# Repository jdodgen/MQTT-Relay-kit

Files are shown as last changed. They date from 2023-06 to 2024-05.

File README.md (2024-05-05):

<h1>MQTT-Relay-kit</h1>
MicroPython and STL's including openSCAD code to make a complete MQTT Client Relay.
<br>
This "kit" includes both the running python code as well as the scad/stl files to make a 3d printed enclosure.
<br>
The parts to build this are:<br>
<b>ESP32-S2 Mini WiFi Board</b><br>
<b>HiLetgo D1 Mini Relay Shield</b> or equivilant<br><pr>
Different relay boards may require changing the lid in the openSCAD code

LOG
<pre>
9-June-2023
This is still a work in progress current: 9-June-2023.<br>
4-May-2024
The hardware is solid, for code improvements see the other MQTT projects

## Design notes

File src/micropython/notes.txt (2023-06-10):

# This is a build on a esp32-s2 on a D1 Mini card
# after powering up
# Press AND HOLD the button labelled 0
# then press and release the RESET button, then release 0
# and it should appear as a serial device.
# This is common to all ESP32-S2's, it's not just "S2 Mini" board.
# note /dev/ttyACM0 will need to have ownership changed or run commands as root sudo
#
# this makes things simpler so do this and logout and in
sudo usermod -a -G dialout $USER

# install tools 
sudo pip install esptool
sudo apt install picocom 
sudo pip install adafruit-ampy

# this is here for cut and paste

sudo chmod 666 /dev/ttyACM0

# if you had done this the above was not needed
sudo usermod -a -G dialout $USER

#now get the current MicroPython installed on the esp32s2
esptool.py --port /dev/ttyACM0 erase_flash
esptool.py --chip esp32s2 --port /dev/ttyACM0 write_flash -z 0x1000 GENERIC_S2-20230426-v1.20.0.bin

# now just press R (RST)  to continue
# R also may be needed after a power cycle

ampy --port /dev/ttyACM0 put main.py
ampy --port /dev/ttyACM0 put run.py
ampy --port /dev/ttyACM0 put relay.py
ampy --port /dev/ttyACM0 put boot.py
ampy --port /dev/ttyACM0 put mqtt_as.py

ampy --port /dev/ttyACM0 put relay_config.py

# test code - had to pull to do a diff
mkdir diff
ampy --port /dev/ttyACM0 get main.py  diff/main.py
ampy --port /dev/ttyACM0 get run.py diff/run.py
ampy --port /dev/ttyACM0 get relay.py diff/relay.py
ampy --port /dev/ttyACM0 get relay_config.py diff/relay_config.py
ampy --port /dev/ttyACM0 get boot.py diff/boot.py
ampy --port /dev/ttyACM0 get mqtt_as.py   diff/mqtt_as.py 

# test stuff

mosquitto_sub -h 192.168.0.173 -t "jed/relay1_status"

# sample test MQTT pubsub
mosquitto_sub -h 192.168.0.173 -t "jed/relay1_status"
mosquitto_pub -h 192.168.0.173 -t "jed/relay1" -m "on"

# REPL 
picocom -b 115200 /dev/ttyACM0
# some needed picocom commands
# CTRL-A CTRK-X  to exit
# import main   to run main or other py
# CTRL-C will stop some code

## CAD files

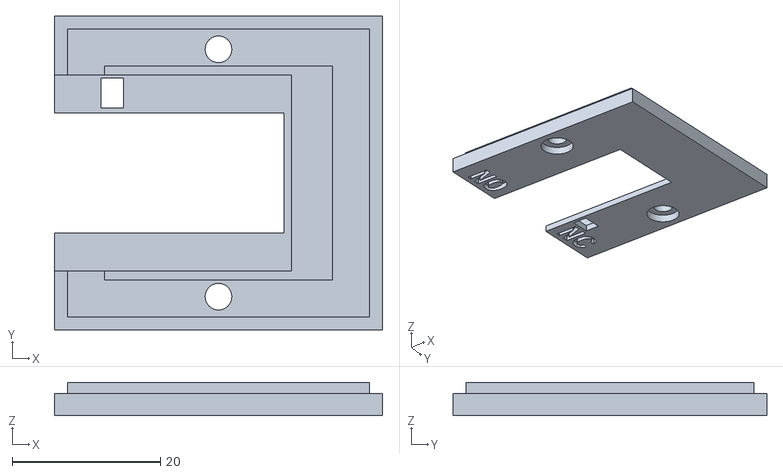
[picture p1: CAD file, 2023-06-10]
src/openscad/s2_relay_lid.stl
44.3 x 42.4 x 4.50

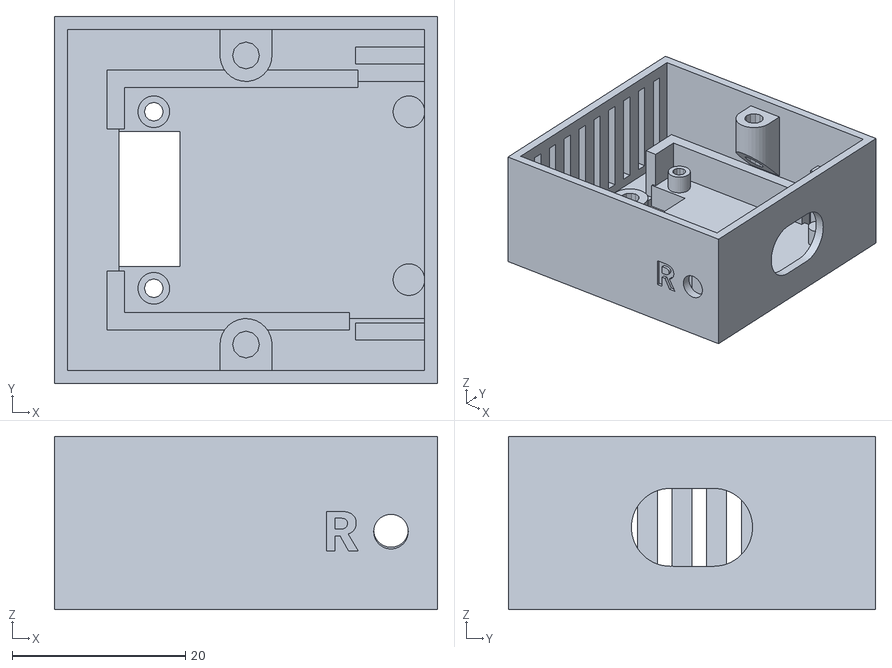
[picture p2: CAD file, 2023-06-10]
src/openscad/s2_relay_base.stl
44.3 x 42.4 x 20.0

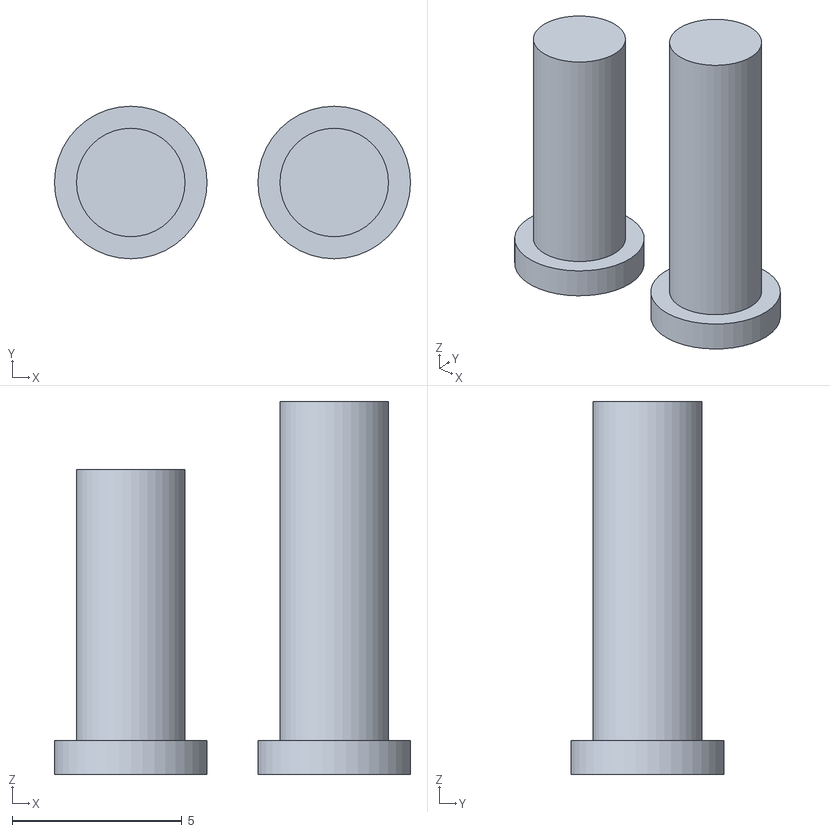
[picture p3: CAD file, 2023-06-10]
src/openscad/s2_relay_buttons.stl
10.5 x 4.50 x 11.0

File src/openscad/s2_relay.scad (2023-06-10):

/*
modular enclosure for ESP32-S2 style of wemos D1 Mini 
current shell lid is for a style of relay 
MIT 
Copyright 2023 James Dodgen

Permission is hereby granted, free of charge, to any person obtaining a copy of this software and associated documentation files (the “Software”), 
to deal in the Software without restriction, including without limitation the rights to use, copy, modify, merge, publish, distribute, 
sublicense, and/or sell copies of the Software, and to permit persons to whom the Software is furnished to do so, subject to the following conditions:

The above copyright notice and this permission notice shall be included in all copies or substantial portions of the Software.

THE SOFTWARE IS PROVIDED “AS IS”, WITHOUT WARRANTY OF ANY KIND, EXPRESS OR IMPLIED, INCLUDING BUT NOT LIMITED TO THE WARRANTIES OF MERCHANTABILITY, 
FITNESS FOR A PARTICULAR PURPOSE AND NONINFRINGEMENT. IN NO EVENT SHALL THE AUTHORS OR COPYRIGHT HOLDERS BE LIABLE FOR ANY CLAIM, 
DAMAGES OR OTHER LIABILITY, WHETHER IN AN ACTION OF CONTRACT, TORT OR OTHERWISE, ARISING FROM, OUT OF OR IN 
CONNECTION WITH THE SOFTWARE OR THE USE OR OTHER DEALINGS IN THE SOFTWARE.

version 1.1
*/

make_somthing = 1;    // 1 base, 2=lid, 3 buttons

if (make_somthing == 1) {
    make_s2_base();
} else if (make_somthing == 2) {
    make_relay_lid();
} else if (make_somthing == 3) {
    make_button();
    translate([6,0,0]) 
        make_button(long=true); // two needed, short for the "O" long for the "RST"
}

Mx_fn = 12; // self tapping 
M3_screw_hole = 3.1; 
M3_clearence_hole = 3.6; 
M3_head_clearence_hole = 6.3;

M2_5_screw_hole = 2.7; 
M2_5_clearence_hole = 3.1; 
M2_5_head_clearence_hole = 6.2;

M2_screw_hole = 2.16; 
M2_clearence_hole = 2.6; 

drill_length = 20;


shell_x = 34.3 + 10;   // adjustments off of S2 D1 Mini
shell_y = 25.4 + 17;
shell_z = 20;
shell_wall_thickness = 1.5;
shell_post_d = 7;



module make_s2_base() {
    difference()
    {
        union()
        {
            make_s2_mini_mount(front_stops=false);
            translate([-(shell_x-s2_x)+shell_wall_thickness,(-(shell_y-s2_y)/2),0])
            {
                shell();
            }
        }
        make_s2_mini_mount_cutout();
    }
}

lid_mount_Loc_1 = [shell_x/2,shell_wall_thickness,shell_z-2];
lid_mount_Loc_2 = [shell_x/2,shell_y-shell_wall_thickness,shell_z-2];

//shell();
module shell()
{
    difference()
    {
        cube([shell_x, shell_y, shell_z]) ;
        translate([shell_wall_thickness, shell_wall_thickness ,shell_wall_thickness])
        {
            cube([shell_x - (shell_wall_thickness*2), shell_y-shell_wall_thickness*2, shell_z]);
        }
        mid_y = shell_y/2;
        make_slot([0,mid_y,3],height=shell_z-5);
        make_slot([0,mid_y+4,3],height=shell_z-5);
        make_slot([0,mid_y-4,3],height=shell_z-5);
        make_slot([0,mid_y+8,3],height=shell_z-5);
        make_slot([0,mid_y-8,3],height=shell_z-5);
        make_slot([0,mid_y-12,3],height=shell_z-5);
        make_slot([0,mid_y+12,3],height=shell_z-5);
        make_slot([0,mid_y-16,3],height=shell_z-5);
        make_slot([0,mid_y+16,3],height=shell_z-5);
        translate([33,0.5,9])
            rotate([90,0,0])
                center_text("R", size=5, extrude=1.2);
        translate([33,shell_y+0.7,9])
            rotate([90,0,0])
                center_text("O", size=5, extrude=1.2);       
        
    }
    lid_mount(lid_mount_Loc_1, rot=0);
    lid_mount(lid_mount_Loc_2, rot=180); 
}

//make_relay_lid();
module make_relay_lid()
{
    hat_x = 32;
    hat_y = 26.5;
    lip_depth = 1.9;
    shrinkage = 0.25;
    lip_width = 5;

    rotate([0,180.0])  // print upside down
    difference()
    {
        union()
        {
            difference()
            {
                union()
                {
                    
                    color("orange") cube([shell_x, shell_y, shell_wall_thickness*2]);
                    difference()
                    {
                        translate([shrinkage+shell_wall_thickness, shrinkage+shell_wall_thickness,-shell_wall_thickness])
                        {
                            slop = (shrinkage+shell_wall_thickness);
                            lip_x = shell_x-slop*2;
                            lip_y = shell_y-slop*2;
                            difference()
                            {
                                cut_out_x = lip_x-lip_width*2;
                                cut_out_y = lip_y-lip_width*2;
                                color("green") cube([lip_x, lip_y, lip_depth]);
                                translate([(lip_x-cut_out_x)/2,(lip_y-cut_out_y)/2,0])
                                    cube([cut_out_x, cut_out_y, lip_depth]);
                            }
                        }
                    }
                }
                translate([shell_x-hat_x,(shell_y - hat_y)/2,-10]) 
                    cube([hat_x, hat_y, 20]);
                lid_mount_clearance_hole(lid_mount_Loc_1, rot=0);
                lid_mount_clearance_hole(lid_mount_Loc_2, rot=180);
            }
            relay_y = 16.2;
            relay_x= 31;
            relay_z = 10;
            difference()
            {
                translate([shell_x-relay_x-2,(shell_y - hat_y-2)/2,shell_wall_thickness+0.3]) 
                    color("purple") cube([relay_x+2,hat_y+2,shell_wall_thickness-0.3]);
                translate([shell_x-relay_x,(shell_y - relay_y)/2,0]) 
                    cube([relay_x,relay_y,relay_z]);
            }
        }
        /// cut outs
        translate([0,0,drill_length/2+shell_wall_thickness]) {
            lid_mount_clearance_hole(lid_mount_Loc_1, rot=0,hole_size=M3_head_clearence_hole);
            lid_mount_clearance_hole(lid_mount_Loc_2, rot=180,hole_size=M3_head_clearence_hole); 
        }
        translate([41,7,2])
            rotate([0,0,90])
                center_text("NO", size=5, extrude=2);  
        translate([41,35,2])
            rotate([0,0,90])
                center_text("NC", size=5, extrude=1.2);  
        // LED cutout
        translate([35,30,-5])
                cube([3,4,20]);
    }
}

module lid_mount(xyz,  width=6, height=8, rot=0) {
    
    echo ("rotate", rot);
    if (rot == 0) { 
        translate([xyz.x+width/2, xyz.y, xyz.z])
            rotate([0,180,rot])
                raw_lid_mount(width=6, height=8);
    } else if ((rot == -90) || (rot == 270 )) {
        translate([xyz.x, xyz.y-width/2, xyz.z])
            rotate([0,180,rot])
                raw_lid_mount(width=6, height=8);
    } else if (rot == 90) {
        translate([xyz.x, xyz.y+width/2, xyz.z])
            rotate([0,180,rot])
                raw_lid_mount(width=6, height=8);
    } else if (rot == 180) {
        translate([xyz.x-width/2, xyz.y, xyz.z])
            rotate([0,180,rot])
                raw_lid_mount(width=6, height=8);
    }
}

//lid_mount([10,10,-2], rot=180); 
//lid_mount_clearance_hole([10,10,-2], rot=180); 
module lid_mount_clearance_hole(xyz,  width=6, height=8, rot=0, hole_size=M3_clearence_hole) {
 
    echo ("rotate", rot);
    if (rot == 0) { 
        translate([xyz.x, xyz.y+width/2, -drill_length/2])
           cylinder(h=drill_length, d=hole_size, $fn=40);
    } else if ((rot == -90) || (rot == 270 )) {
        translate([xyz.x+width/2, xyz.y, -drill_length/2])
            cylinder(h=drill_length, d=hole_size, $fn=40);
    } else if (rot == 90) {
        translate([xyz.x-width/2, xyz.y, -drill_length/2])
            cylinder(h=drill_length, d=hole_size, $fn=40);
    } else if (rot == 180) {
        translate([xyz.x, xyz.y-width/2, -drill_length/2])
            cylinder(h=drill_length, d=hole_size, $fn=40);   
    }
}

//raw_lid_mount();
module raw_lid_mount(width=6, height=8) {
    raw_height =20;
    //screw_depth= height*0.75;
    difference() 
    { 
        cube([width, width,raw_height]);			
        // chop off at 45 
        rotate([-45,0,0]) 
            translate([0,-50,height])
                cube([width, 100, raw_height*2]);		
        // screw hole
        translate([width/2, width/2,-2]) 
            cylinder(h=raw_height, d=M3_screw_hole, $fn=Mx_fn);                  
        translate([width/2,width/2,-2]) 
            fillet(180,width/2, raw_height+2, $fn=30);
        translate([0,width/2,-2]) 
                fillet(-90,width/2, raw_height+2, $fn=30);
    }                   
}

*difference() {
    make_s2_mini_mount(button_guides=false);
    make_s2_mini_mount_cutout();
    //translate([10,-50,0]) cube([100,100,100]);
}

/* 
START Wemos S2 Mini mount code
*/
s2_y=25.4;
s2_x=34.3;
s2_thickness=4;

total_height = s2_thickness+3;
usb_c_hole_width = 14;
usb_c_hole_height = 9;

hole_offset_x = 3; 
hole1_offset_y = 2.5;
hole2_offset_y= hole1_offset_y+20.4;
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

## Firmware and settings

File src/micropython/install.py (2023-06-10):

import os
# this configures and installs router software
# change relay_config_template to your system/network
# the {}'s are replaced with MQTT Topic name
relay_config_template = """
ssid = 'JEDguest' 
passwd = '9098673852'
server = 'home-broker.local'
sub_topic = "{}"
pub_topic = "{}_status"
relay_pin = 35
"""
print("each relay must have a unique topic name")
print("input topic")
topic=input()

cooked_cfg = relay_config_template.format(topic,topic)
with open('relay_config.py', 'w') as f:
    f.write(cooked_cfg)

print("install micropython? (Y,n)")
ans = input()
if (ans.upper() != "N"):
    os.system("esptool.py --port /dev/ttyACM0 erase_flash")
    os.system("esptool.py --chip esp32s2 --port /dev/ttyACM0 write_flash -z 0x1000 GENERIC_S2-20230426-v1.20.0.bin")

code = [
"run.py",
"main.py",
"relay.py",
"mqtt_as.py",
"boot.py",
"relay_config.py",
]

print("now pushing python code")
for c in code:
    print("installing", c)
    os.system("ampy --port /dev/ttyACM0 put "+c)

os.system("ampy --port /dev/ttyACM0 ls")

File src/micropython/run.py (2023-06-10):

# simple relay controler
# built from mqtt_as event demo
# modifications Jim Dodgen 2023
# MIT Licence

from mqtt_as import MQTTClient, config
import relay_config
from relay import relay
import uasyncio as asyncio
import time
import ntptime


# Local configuration
config['ssid'] = relay_config.ssid  # Optional on ESP8266
config['wifi_pw'] = relay_config.passwd
config['server'] = relay_config.server  # Change to suit e.g. 'iot.eclipse.org'

r = relay(relay_config.relay_pin)
def stat_msg():
    t = time.localtime()
    time_string = str(t[0])+"-"+str(t[1])+"-"+str(t[2])+"-"+str(t[3])+"-"+str(t[4])
    print(time_string)
    return bytes(r.current_state()+"/"+time_string, 'utf-8')

async def messages(client):  # Respond to incoming messages
    async for topic, msg, retained in client.queue:
        top = topic.decode('utf-8')
        cmd = msg.decode('utf-8')
        print(top, cmd, retained)
        if (cmd == "on"):
            r.turn_on()
        else:
            r.turn_off()
        
        await client.publish(relay_config.pub_topic, stat_msg(), qos = 1, retain=True)

async def up(client):  # Respond to connectivity being (re)established
    while True:
        await client.up.wait()  # Wait on an Event
        client.up.clear()
        print("subscribing")
        await client.subscribe(relay_config.sub_topic, 1)  # renew subscriptions

async def main(client):
    while True:
        print("checking connection")
        try:
            await client.connect()
        except:
            pass
        else:
            break
    ntptime.settime()
    for coroutine in (up, messages):
        asyncio.create_task(coroutine(client))
    await asyncio.sleep(5)
    #stat_msg = bytes(r.current_state()+"/"+str(time.time()), 'utf-8')
    await client.publish(relay_config.pub_topic, stat_msg(), qos = 1, retain=True)
    while True:
        await asyncio.sleep(60)
        print('publish current state', r.current_state())
        # If WiFi is down the following will pause for the duration.
        #await client.publish('result', '{}'.format(n), qos = 1)
        #await client.publish(relay_config.pub_topic, bytes(str(n), 'utf-8'), qos = 1)
        #stat_msg = bytes(r.current_state()+"/"+str(time.time()), 'utf-8')
        await client.publish(relay_config.pub_topic, stat_msg(), qos = 1, retain=True)
       

print("starting")

config["queue_len"] = 1  # Use event interface with default queue size
MQTTClient.DEBUG = True  # Optional: print diagnostic messages
client = MQTTClient(config)
try:
    asyncio.run(main(client))
finally:
    client.close()  # Prevent LmacRxBlk:1 errors
print("example exiting")
